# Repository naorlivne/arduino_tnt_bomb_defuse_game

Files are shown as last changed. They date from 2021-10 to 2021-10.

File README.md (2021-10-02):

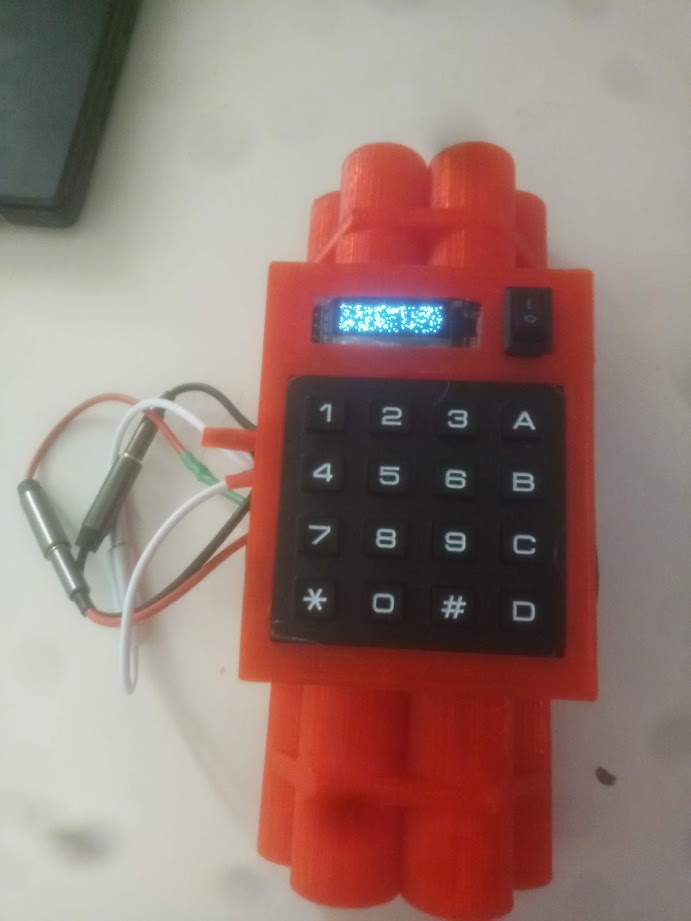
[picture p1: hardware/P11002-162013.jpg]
bomb defuse starting up


# arduino_tnt_bomb_defuse_game
A defuse the bomb type game, perfect for airsoft/paintball/etc, has multiple ways of disabling the bomb for extra fun:

1. Once turned on you type in a 4 digit disarm code
2. A 90 second countdown then starts (can be changed via changing a variable in the codebase)
3. At any point in this 90 second you can type in the disarm code to stop the bomb, but if you mistype you go boom
4. There are also 3 wires (optionally multiple colored one, depending on how you build it) that can be "cut" via unplugging them:
    * One wire will defuse the bomb
    * One wire will make you go boom
    * One wire will dramatically increase the countdown speed so you won't have long to try again

Once the bomb go boom both a visual warning and an audioable (rather annoying one) goes off letting both teams know the round is over, then you simply turn it off and on again and have another round.

## BOM - (bill of materials)
* 1 ardiuno uno
* 3 AAA batteries
* 1 battery holder for 3 AAA batteries
* 1 3v active buzzer ( I used https://www.aliexpress.com/item/1005002537526187.html?spm=a2g0s.9042311.0.0.27424c4dKe6Iv1 )
* 1 4x4 metrix keypad (I used https://www.aliexpress.com/item/1005002717991471.html?spm=a2g0s.9042311.0.0.27424c4dSMUNud )
* 1 SSD1306 128X32 OLED module ( I used https://www.aliexpress.com/item/32672327708.html?spm=a2g0s.9042311.0.0.27424c4d4H5K10 )
* 1 rocker 10*15mm toggle switch  ( I used https://www.aliexpress.com/item/1005001998277516.html?spm=a2g0s.9042311.0.0.27424c4dK9r7lB )
* 3 2.5 aux headset extention cables ( I used https://www.aliexpress.com/item/1005002637786689.html?spm=a2g0s.9042311.0.0.27424c4dolIJXD )
* lots of Dupont cables

## Needed tools
* 3d printer (or 3d printing service)
* Hot glue gun & glue sticks
* Soldering iron & tin
* Electric insolation tape and/or electric shrink-wrap
* wire cutter

## Software

### Install liberies:
* Keypad (version 3.1.1)
* Adafruit SSD1306 (version 2.4.6)
* Adafruit GFX Library (version 1.10.10)
* Adafruit BusIO (version 1.9.1)

### install codebase
Flash your arudino with the code that's located in `software/arduino_tnt_defuse_game/arduino_tnt_defuse_game.ino`

## Hardware
3D print the two STL files that are located in `hardware`

## Electronics
Connect your ardiuno according to the diagram in `electronics/tnt_game_electronics.jpg`

## Putting it all togther:
1. Install the liberies described above to your arudino
2. Flash the codebase to the arudino
3. 3d print the 2 STL files described above
4. Cut your aux headset extention cables in half so you have 6 cables total, 3 with male & 3 female, thread each through a hole on the side of the 3d printed case
5. Place the toggle switch, the on the top in it's open space (you'll need to do this before wiring it up) & hot glue it into place
6. Wire the arudino as described above (some soldering required as not everything is Dupont)
7. Place the OLED screen and keypad in place and hotglue them to the top
8. Close the top on the case

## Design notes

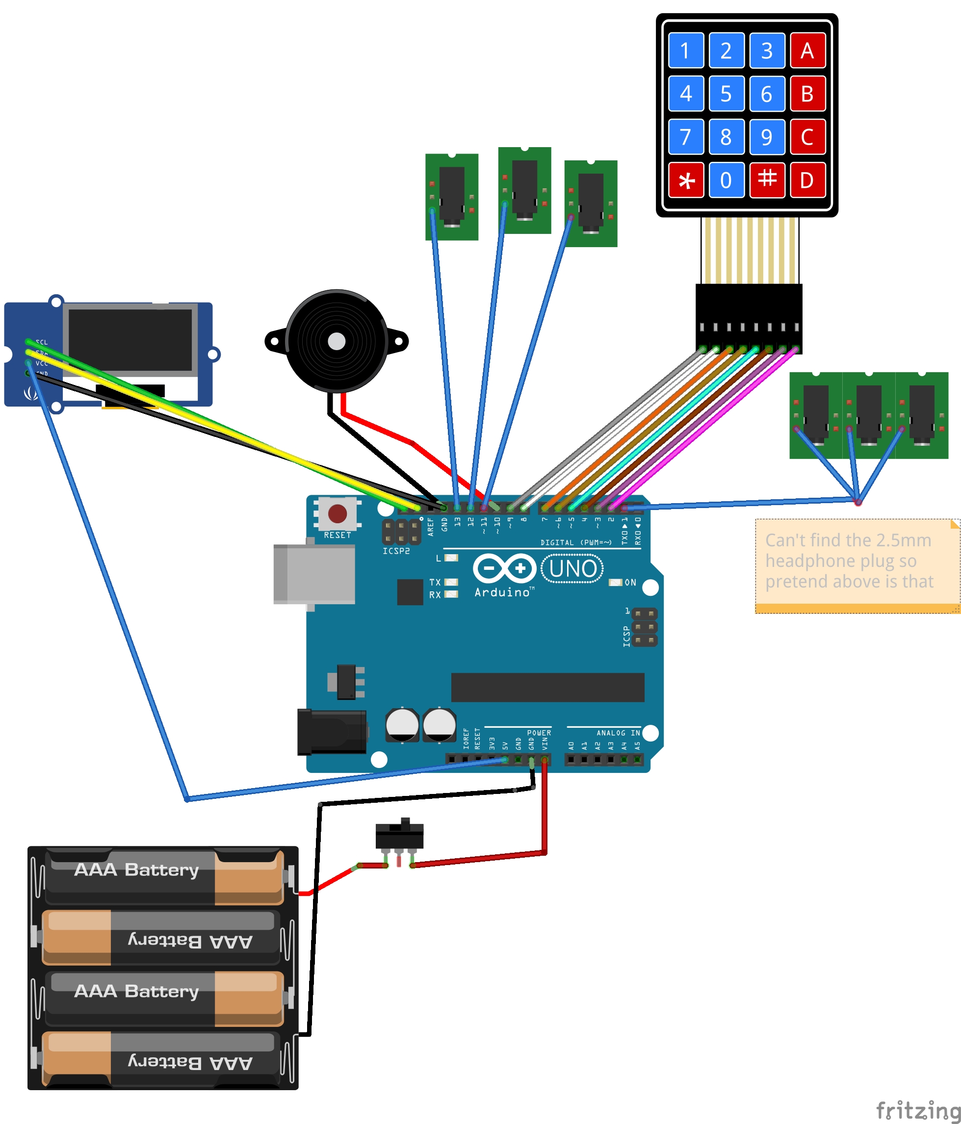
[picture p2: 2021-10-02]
electronics/tnt_game_electronics.jpg

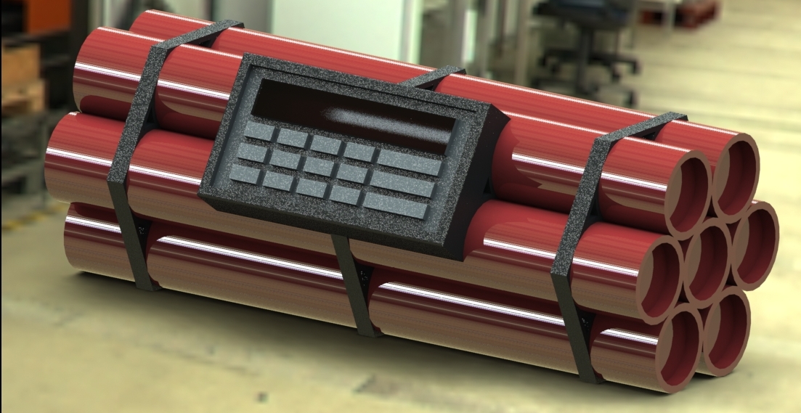
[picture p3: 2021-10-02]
hardware/bomb_rander.JPG

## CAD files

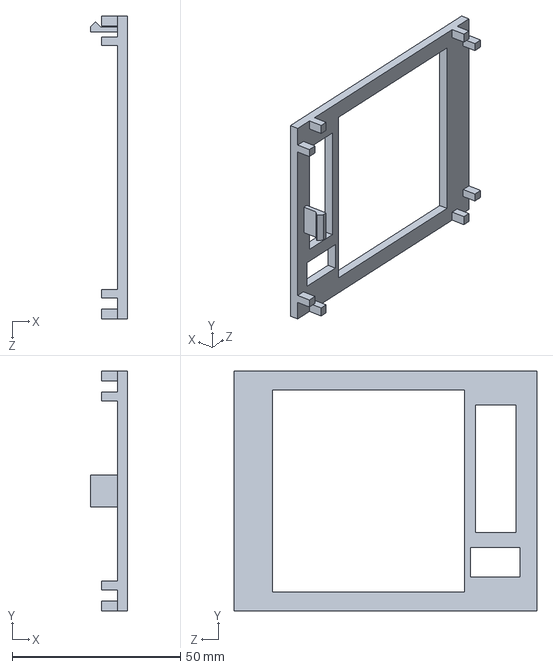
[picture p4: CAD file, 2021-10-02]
hardware/tnt_5_mk3_shell_upper.SLDPRT
11.0 x 71.2 x 90.0 mm

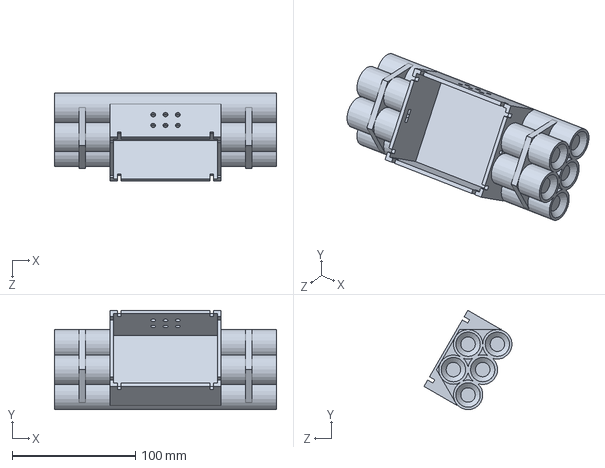
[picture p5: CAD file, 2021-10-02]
hardware/tnt_5_mk3_shell_lower.SLDPRT
180.0 x 80.5 x 71.4 mm

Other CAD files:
hardware/tnt_5_mk3_shell_lower.STL
hardware/tnt_5_mk3_shell_upper.STL

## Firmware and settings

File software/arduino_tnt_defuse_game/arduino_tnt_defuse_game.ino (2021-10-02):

#include <Keypad.h>
#include <SPI.h>
#include <Wire.h>
#include <Adafruit_GFX.h>
#include <Adafruit_SSD1306.h>


const byte ROWS = 4; //four rows
const byte COLS = 4; //four columns

const int buzzer_pin =  10;// the number of the buzzer pin
const int cuttable_wires_out =  1;// pin of fake-cuttable wire output
const int cuttable_wires_in[]={11, 12, 13}; // pins of fake-cuttable wires input

char keys[ROWS][COLS] = {
  {'1','2','3','A'},
  {'4','5','6','B'},
  {'7','8','9','C'},
  {'*','0','#','D'}
};

byte rowPins[ROWS] = {5, 4, 3, 2}; //connect to the row pinouts of the keypad
byte colPins[COLS] = {9, 8, 7, 6}; //connect to the column pinouts of the keypad

// change to true if you want buzzing on key presses
bool buzz_on_key_press = false;

// set bomb starting state to armed
String bomb_state = "arming";

// initial countdown seconds
int countdown_seconds = 90;

// initial delay speed time, the lower it is the faster the countdown will be
int delay_speed = 25;

// starting delay
int current_delay = 0;

// location of key
int key_location = 0;

String defuse_key = "";
String defuse_try_key = "";

#define SCREEN_WIDTH 128 // OLED display width, in pixels
#define SCREEN_HEIGHT 32 // OLED display height, in pixels
Adafruit_SSD1306 display(SCREEN_WIDTH, SCREEN_HEIGHT, &Wire, -1);

//Create an object of keypad
Keypad keypad = Keypad( makeKeymap(keys), rowPins, colPins, ROWS, COLS );

void setup(){
  if(!display.begin(SSD1306_SWITCHCAPVCC, 0x3C)) { // Address 0x3D for 128x64
    for(;;);
  }
  display.clearDisplay();
  display.setTextSize(1);
  display.setTextColor(WHITE);
  display.setCursor(0, 0);

  // initilize pin modes

  pinMode(buzzer_pin, OUTPUT);
  pinMode(cuttable_wires_out, OUTPUT);
  for (byte i = 0; i < 3; i = i + 1) {
    pinMode(cuttable_wires_in[i], INPUT_PULLUP);
  }

}


// ring buzzer
void ring_buzzer_on(){
  digitalWrite(buzzer_pin, HIGH);
}

// stop ringing buzzer
void ring_buzzer_off(){
  digitalWrite(buzzer_pin, LOW);
}

bool cuttable_wires_state(int pin_number){
  if (digitalRead(cuttable_wires_in[pin_number]) == HIGH){
    return true;
  }
  else {
    return false;
    }
  }
  
void loop(){
  digitalWrite(cuttable_wires_out, HIGH);
  if (bomb_state == "arming") {
     char key = keypad.getKey();// Read the key
    // Print if key pressed
    if (key){
      if (buzz_on_key_press == true){
        ring_buzzer_on();
        delay(100);
        ring_buzzer_off();
      }
      if (key_location < 4) {
      key_location = key_location + 1;
      defuse_key = defuse_key + key;
      display.println("enter defuse code:");
      display.display();
      display.setCursor(0, 16);
      display.println(defuse_key);
      display.display();
      display.clearDisplay();
      display.setCursor(0, 0);
      }
  }
    if (key_location == 4){
      bomb_state = "counting";  
      }
  }
  else if (bomb_state == "counting") {
      key_location = 0;
      while (countdown_seconds != 0){
        char key = keypad.getKey();
        if (key){
            if (buzz_on_key_press == true){
              ring_buzzer_on();
              delay(100);
              ring_buzzer_off();
            }
            if (key_location < 4) {
            key_location = key_location + 1;
            defuse_try_key = defuse_try_key + key;
            }
            if (key_location == 4) {
              if (defuse_try_key == defuse_key){
                bomb_state = "defused";
                break;
                }
              else {
              bomb_state = "exploding";
              break;
              }
            }
        }
        display.println("counting down: " + String(countdown_seconds));
        display.display();
        display.setCursor(0, 16);
        display.println("defuse code: " +  String(defuse_try_key));
        display.display();
        display.clearDisplay();
        display.setCursor(0, 0);
        delay(1);
        if (current_delay == delay_speed){
          countdown_seconds = countdown_seconds -1;
          current_delay = 0;
        }
        current_delay = current_delay + 1;
        if (cuttable_wires_state(0) == false){
          bomb_state = "exploding";
          break;
       }
        if (cuttable_wires_state(1) == false){
          delay_speed = 10;
        }
        if (cuttable_wires_state(2) == false){
          bomb_state = "defused";
          break;
        }
      }
      if (countdown_seconds == 0){
      bomb_state = "exploding";  
      }
  }
  else if (bomb_state == "exploding") {
    ring_buzzer_on();
    display.println("bomb exploded");
    display.display();
    display.clearDisplay();
    display.setCursor(0, 0);
    delay(100);
    ring_buzzer_off();
  }
    else if (bomb_state == "defused") {
    display.println("bomb defused");
    display.display();
    display.clearDisplay();
    display.setCursor(0, 0);
  }
}

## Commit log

2021-09-02 basic framework
2021-09-02 adding hardware and basic readme and test screen and keypad code
    [tnt_5_mk3_shell_lower.SLDPRT, tnt_5_mk3_shell_lower.STL]
2021-10-02 added electronics schema
    [tnt_game_electronics.fzz]
2021-10-02 hardware changes
    [tnt_5_mk3_shell_lower.SLDPRT, tnt_5_mk3_shell_upper.SLDPRT, tnt_5_mk3_shell_upper.STL]
